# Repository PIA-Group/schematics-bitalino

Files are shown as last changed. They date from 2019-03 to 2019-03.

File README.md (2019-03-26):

# BITalino Schematics

PCB schematics and physical drawings for the original BITalino (https://www.bitalino.com) biomedical development toolkit, which includes Molex Sherlock connectors footprint and pin
breakout. Source files (.brd & .sch) can be opened with AutoDesk's EAGLE PCB design software: https://www.autodesk.com/products/eagle/overview

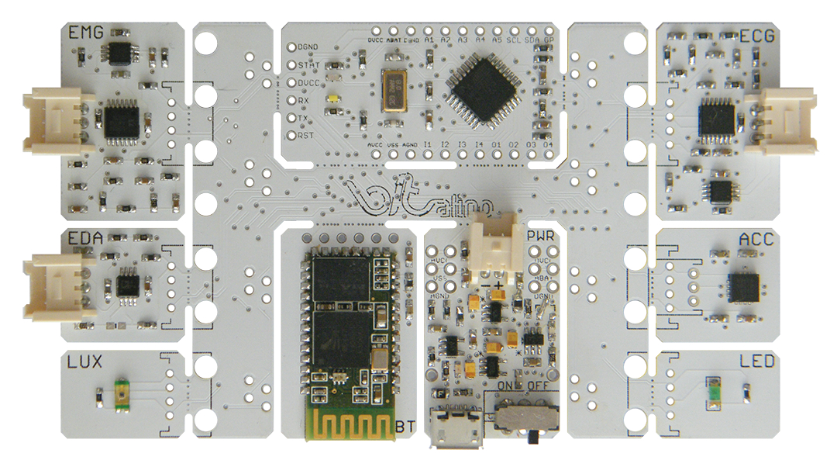
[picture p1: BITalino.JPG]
BITalino All-in-One Board


## Publications

Diana Baptista, Hugo Plácido da Silva and Ana Fred. [Experimental Characterization and Analysis of the BITalino Platforms Against a Reference Device](https://ieeexplore.ieee.org/abstract/document/8037344/). In *Proc. of the IEEE Engineering in Medicine and Biology Society Annual Int’l Conf. (EMBC)*, pp. 2418-2421, 2017

Hugo Plácido da Silva, Carlos Carreiras, André Lourenço, Ana Fred, Rui César das Neves and Rui Ferreira. [Off-the-person electrocardiography: performance assessment and clinical correlation](https://link.springer.com/article/10.1007%2Fs12553-015-0098-y). *Health and Technology*, 4(4), pp. 309-318, Springer, 2015

Hugo Plácido da Silva, Ana Fred and Raúl Martins. [Biosignals for Everyone](https://ieeexplore.ieee.org/xpl/articleDetails.jsp?arnumber=6926682). *IEEE Pervasive Computing*, 13(4):64-71, 2014

Hugo Plácido da Silva, André Lourenço, Ana Fred and Raúl Martins. [BIT: Biosignal Igniter Toolkit](https://sciencedirect.com/science/article/pii/S0169260714000984). *Computer Methods and Programs in Biomedicine*, 115(1):20-32, 2014

Hugo Plácido da Silva, José Guerreiro, André Lourenço, Ana Fred and Raúl Martins. [BITalino: A novel hardware framework for physiological computing](https://www.researchgate.net/publication/260987402_BITalino_A_Novel_Hardware_Framework_for_Physiological_Computing). In *Proc. of the Int’l Conf. on Physiological Computing Systems (PhyCS)*, pp. 246-253, 2014

José Guerreiro, André Lourenço, Hugo Plácido da Silva and Ana Fred. [Performance comparison of low-cost hardware platforms targeting physiological computing applications](https://it.pt/papconf_abs_p.asp?ID_PaperConference=14722&id=4). In *Proc. of the Conf. on Electronics, Telecommunications and Computers (CETC)*, 2013

José Guerreiro, Raúl Martins, Hugo Plácido da Silva, André Lourenço and Ana Fred. [BITalino: A multimodal platform for physiological computing](https://www.researchgate.net/publication/259177489_BITalino_A_Multimodal_Platform_for_Physiological_Computing). In *Proc. of the Int’l Conf. on Informatics in Control, Automation and Robotics (ICINCO)*, pp. 500-506, 2013

Priscila Alves, Hugo Plácido da Silva, André Lourenço and Ana Fred. [BITalino: A biosignal acquisition system based on the Arduino](https://lx.it.pt/~afred/papers/BITalino.pdf). In *Proc. of the Int'l Conf. on Biomedical Electronics and Devices (BIODEVICES)*, pp. 261-264, 2013

## License

See LICENSE for more details.

## Disclaimer

This work is distributed in the hope it will be useful and provided
to you "as is", but WITHOUT ANY WARRANTY, without even the implied
warranty of MERCHANTABILITY or FITNESS FOR A PARTICULAR PURPOSE. This
work is NOT intended for medical diagnosis. We expressly disclaim any
liability whatsoever for any direct, indirect, consequential, incidental
or special damages, including, without limitation, lost revenues, lost
profits, losses resulting from business interruption or loss of data,
regardless of the form of action or legal theory under which the
liability may be asserted, even if advised of the possibility of such
damages.

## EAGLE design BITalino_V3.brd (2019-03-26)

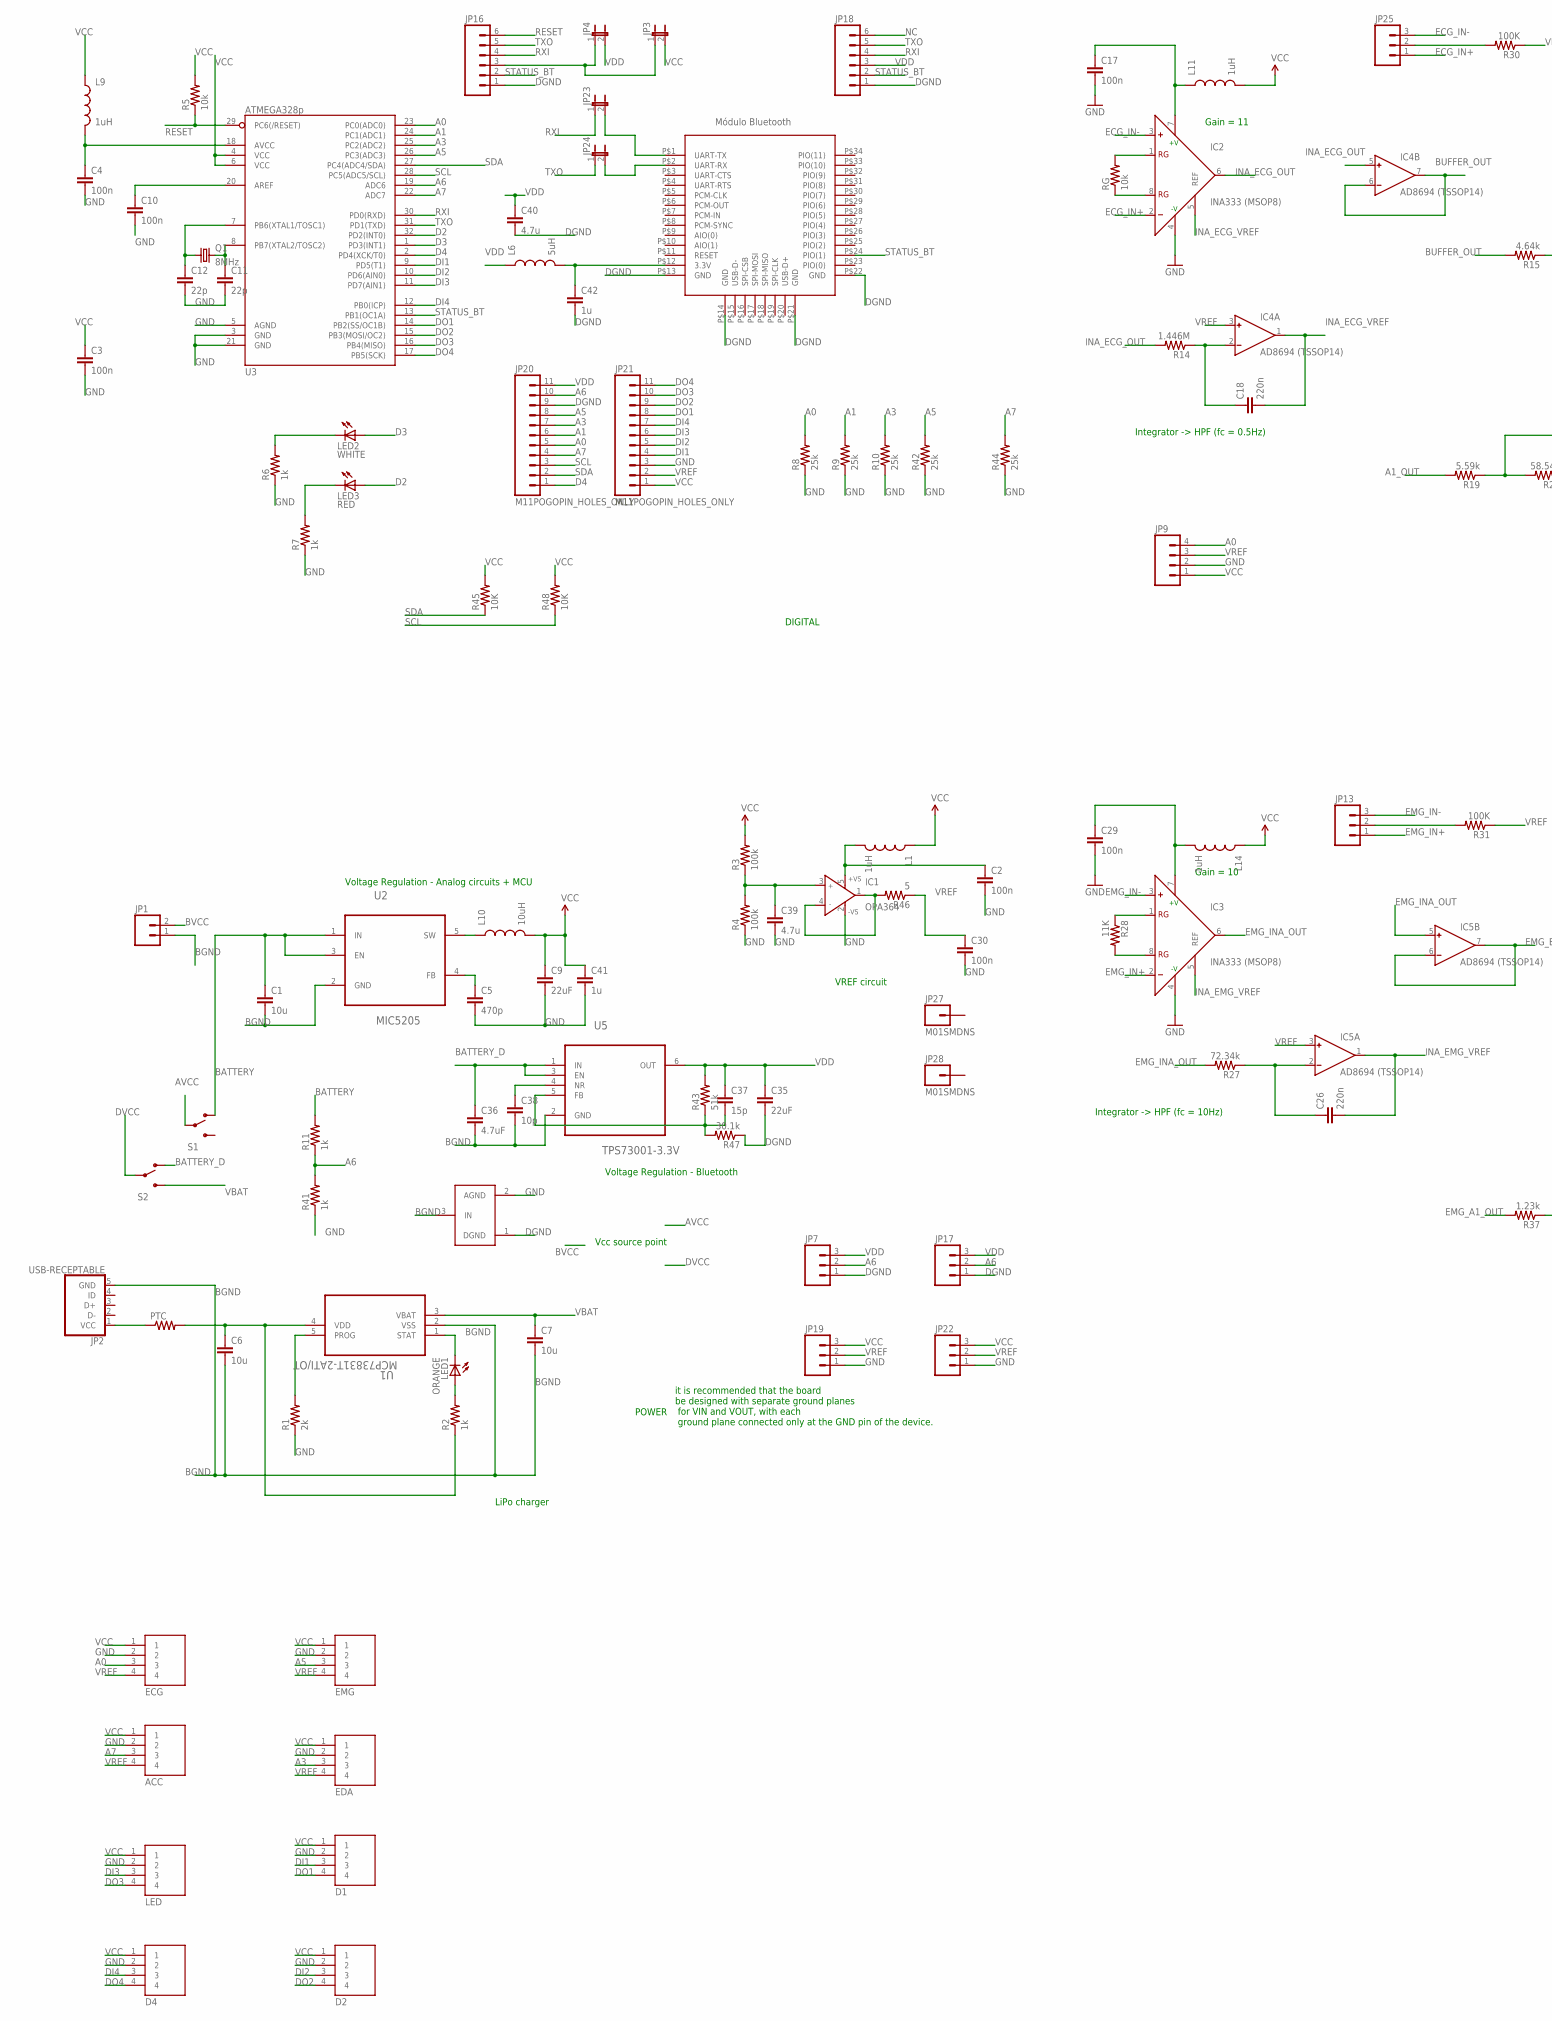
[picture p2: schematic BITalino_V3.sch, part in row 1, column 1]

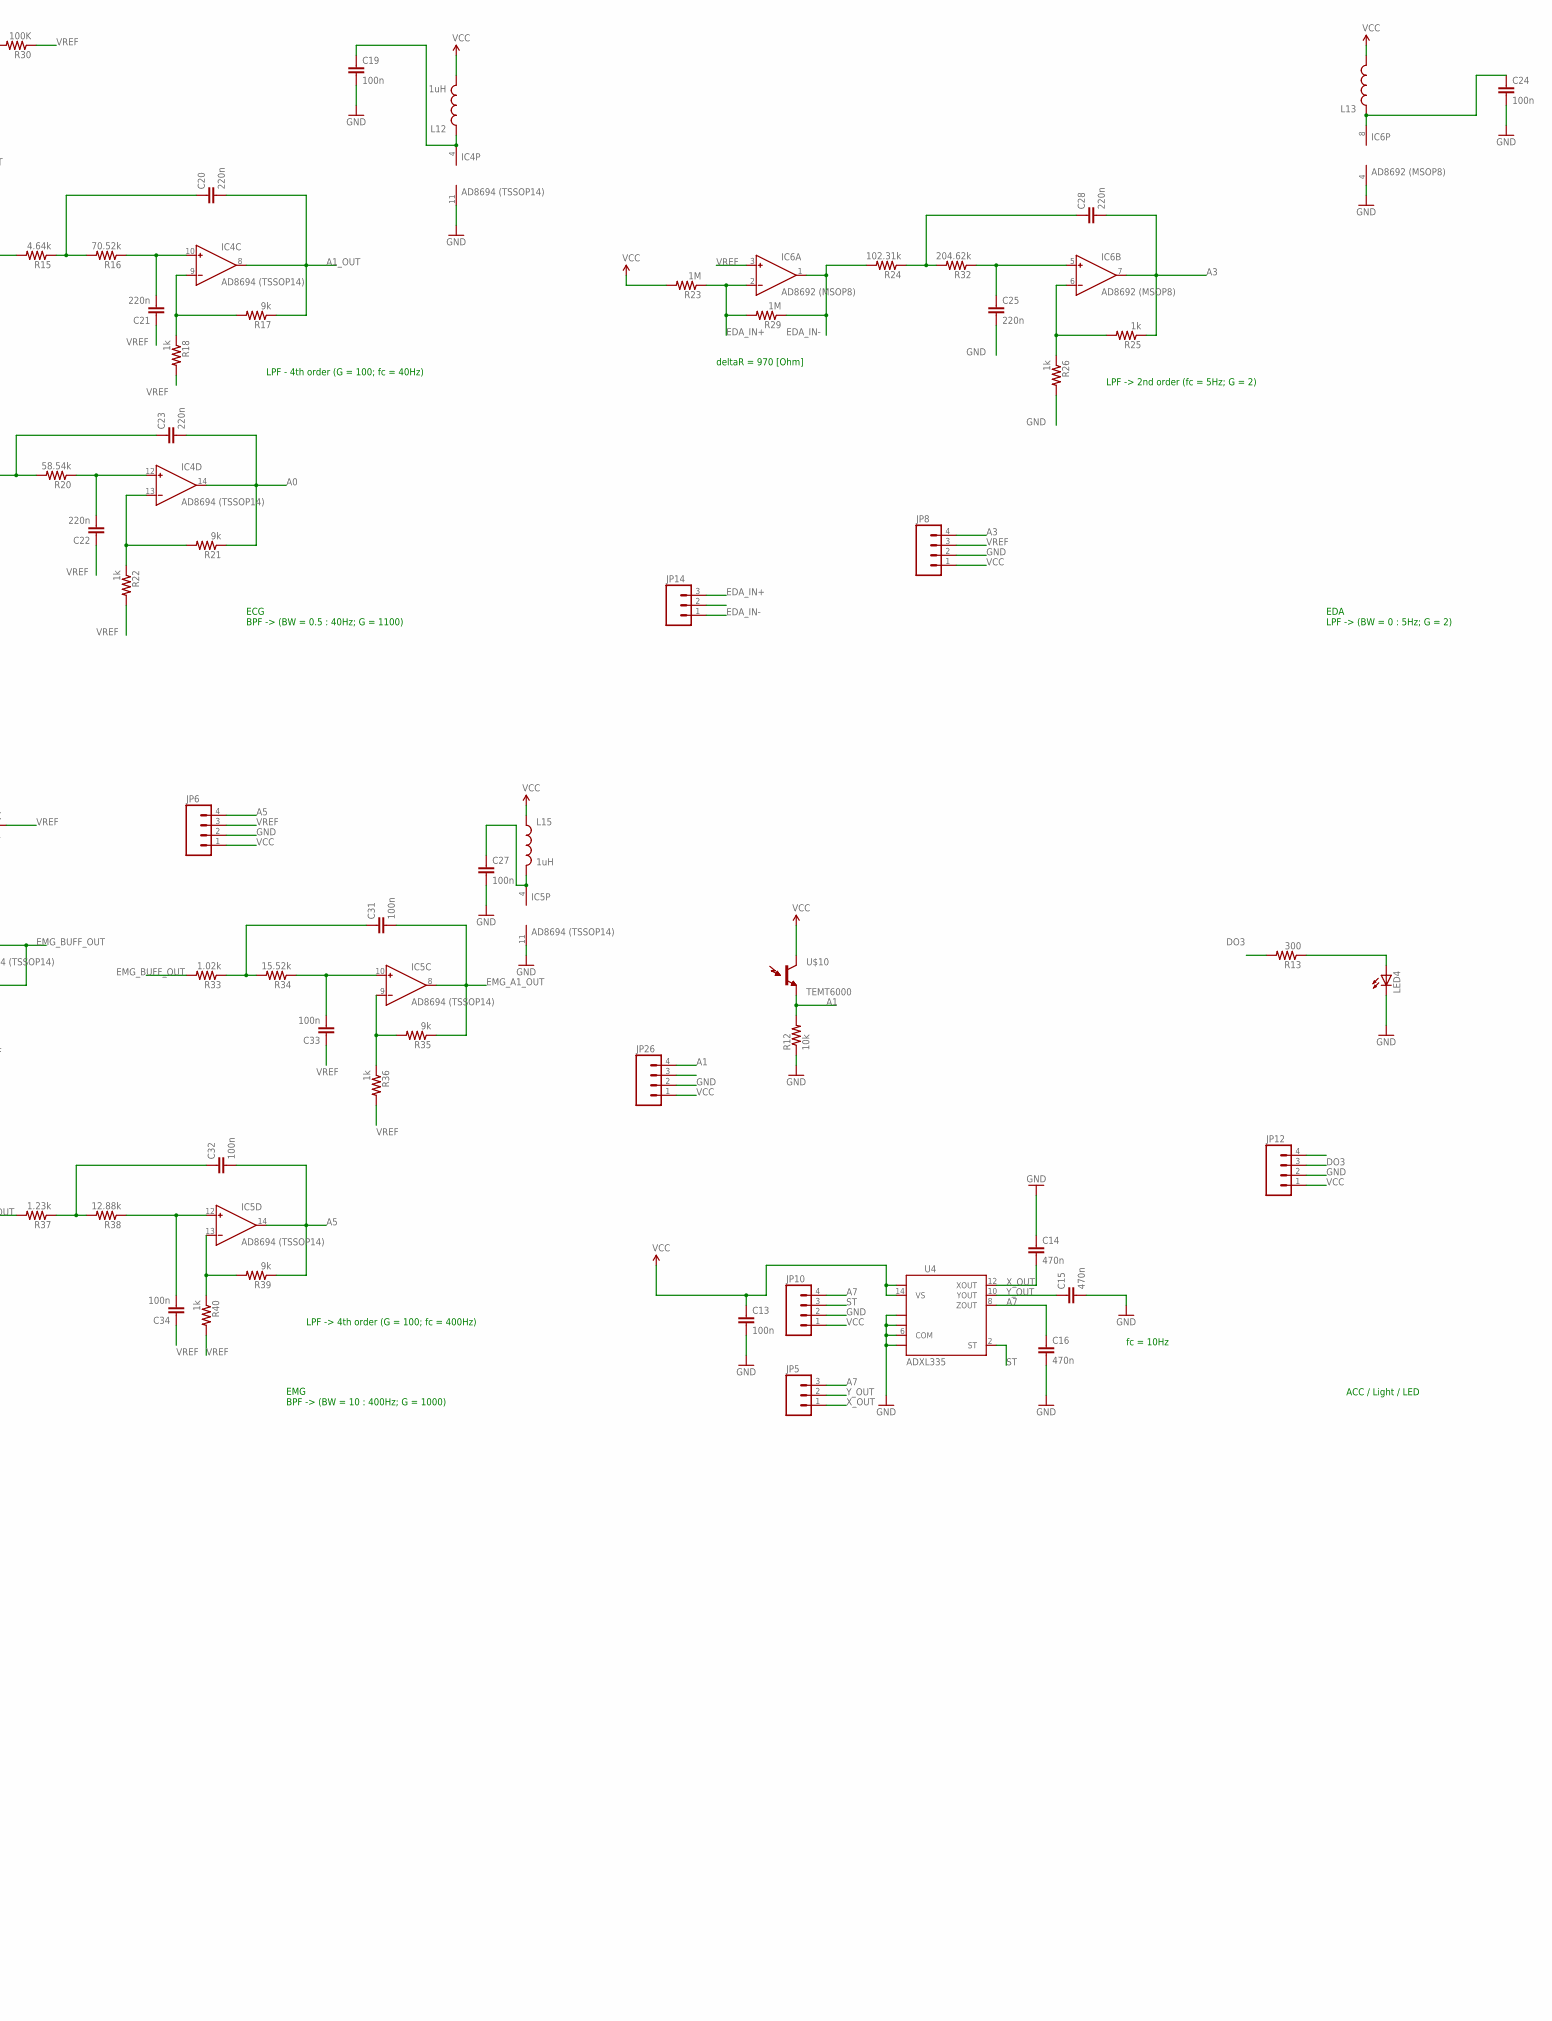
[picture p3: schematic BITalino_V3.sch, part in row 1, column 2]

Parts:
ACC: RJ22; SMD
C1, C6, C7: 10u; 0805
C2, C3, C4, C10, C13, C17, C19, C24, C27, C29, C30, C31, C32, C33, C34: 100n; 0603-CAP
C5: 470p; 0603-CAP
C9, C35: 22uF; 0805
C11, C12: 22p; 0603-CAP
C14, C15, C16: 470n; 0603-CAP
C18, C20, C21, C22, C23, C25, C26, C28: 220n; 0603-CAP
C36: 4.7uF; 0805
C37: 15p; 0603-CAP
C38: 10p; 0603-CAP
C39, C40: 4.7u; 0603-CAP
C41, C42: 1u; 0603-CAP
D1, D2, D4: RJ22; SMD
ECG: RJ22; SMD
EDA: RJ22; SMD
EMG: ECG; SMD
IC1: OPA364; SOT23-5
IC2, IC3: INA333 (MSOP8); MSOP08
IC4, IC5: AD8694 (TSSOP14); TSSOP14
IC6: AD8692 (MSOP8); MSOP08
JP1: M02-JST-2-PTH-NO_SILK; JST-2-PTH-NS
JP2: USB-RECEPTABLE; FCI-10103594-0001LF
JP3, JP4, JP23, JP24: JUMPER-2SMD-NO-NS; SJ_2S-NO-NS
JP5, JP13, JP14, JP25: M03JST-PTH; JST-3-PTH
JP6, JP8, JP9, JP10, JP12, JP26: M04JST-PTH; JST-4-PTH
JP7, JP17, JP19, JP22: M031X03_NO_SILK; 1X03_NO_SILK
JP16, JP18: M06POGOPIN_HOLES_ONLY; 1X06_HOLES_ONLY
JP20, JP21: M11POGOPIN_HOLES_ONLY; 1X11_HOLES_ONLY
JP27, JP28: M01SMDNS; 1X01NS
L1, L9, L11, L12, L14, L15: 1uH; 0603
L6: 5uH; 0805
L10: 10uH; 0805
L13: INDUCTOR0603; 0603
LED: RJ22; SMD
LED1: ORANGE; LED-0603
LED2: WHITE; LED-0603
LED3: RED; LED-0603
LED4: LED1206; LED-1206
PTC: RESISTOR0805-RES; 0805
Q1: 8MHz; CTS406
R1: 2k; 0603-RES
R2, R6, R7, R11, R18, R22, R25, R26, R36, R40, R41: 1k; 0603-RES
R3, R4: 100k; 0603-RES
R5, R12: 10k; 0603-RES
R8, R9, R10, R42, R44: 25k; 0603-RES
R13: 300; 0603-RES
R14: 1.446M; 0603-RES
R15: 4.64k; 0603-RES
R16: 70.52k; 0603-RES
R17, R21, R35, R39: 9k; 0603-RES
R19: 5.59k; 0603-RES
R20: 58.54k; 0603-RES
R23, R29: 1M; 0603-RES
R24: 102.31k; 0603-RES
R27: 72.34k; 0603-RES
R28: 11K; 0603-RES
R30, R31: 100K; 0603-RES
R32: 204.62k; 0603-RES
R33: 1.02k; 0603-RES
R34: 15.52k; 0603-RES
R37: 1.23k; 0603-RES
R38: 12.88k; 0603-RES
R43: 51k; 0603-RES
R45, R48: 10K; 0603-RES
R46: 5; 0603-RES
R47: 30.1k; 0603-RES
RG: 10k; 0603-RES
S1, S2: SWITCH-SPSTPTH; SWITCH-SPDT
U1: MCP73831T-2ATI/OT; SOT95P300X145-5N
U2: MIC5205; SOT95P280X130-5N; MPN ADP2108AUJZ-3.3-R7
U3: ATMEGA328p; TQFP32-08
U4: ADXL335; LFCSP-16
U5: TPS73001-3.3V; SOT95P280X145-6N
U$1: BLUETOOTH
U$2: GND_CONNECT
U$10: TEMT6000; TEMT6000-SEN

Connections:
A0: C23.2, ECG.3, IC4.14 (OUT), JP9.4, JP20.5, R8.2, R21.1, U3.23 (PC0(ADC0))
A1: JP20.6, JP26.4, R9.2, R12.2, U3.24 (PC1(ADC1)), U$10.EMITTER (E1)
A1_OUT: C20.2, IC4.8 (OUT), R17.1, R19.2
A3: C28.2, EDA.3, IC6.7 (OUT), JP8.4, JP20.7, R10.2, R25.1, U3.25 (PC2(ADC2))
A5: C32.2, EMG.3, IC5.14 (OUT), JP6.4, JP20.8, R39.1, R42.2, U3.26 (PC3(ADC3))
A6: JP7.2, JP17.2, JP20.10, R11.1, R41.2, U3.19 (ADC6)
A7: ACC.3, C16.1, JP5.3, JP10.4, JP20.4, R44.2, U3.22 (ADC7), U4.8 (ZOUT)
AVCC: S1.2
BATTERY: C1.1, R11.2, S1.1 (O), U2.1 (IN), U2.3 (EN)
BATTERY_D: C36.1, S2.1 (O), U5.1 (IN), U5.3 (EN)
BGND: C1.2, C6.2, C7.2, C36.2, C38.2, JP1.1, JP2.5 (GND), U1.2 (VSS), U2.2 (GND), U5.2 (GND), U$2.3 (IN)
BUFFER_OUT: IC4.6 (IN-), IC4.7 (OUT), R15.2
BVCC: JP1.2
D2: LED3.A, U3.32 (PD2(INT0))
D3: LED2.A, U3.1 (PD3(INT1))
D4: JP20.1, U3.2 (PD4(XCK/T0))
DGND: C35.2, C40.2, C42.2, JP7.1, JP16.1, JP17.1, JP18.1, JP20.9, R47.1, U$1.P$13 (GND), U$1.P$14 (GND), U$1.P$21 (GND), U$1.P$22 (GND), U$2.1 (DGND)
DI1: D1.3, JP21.4, U3.9 (PD5(T1))
DI2: D2.3, JP21.5, U3.10 (PD6(AIN0))
DI3: JP21.6, LED.3, U3.11 (PD7(AIN1))
DI4: D4.3, JP21.7, U3.12 (PB0(ICP))
DO1: D1.4, JP21.8, U3.14 (PB2(SS/OC1B))
DO2: D2.4, JP21.9, U3.15 (PB3(MOSI/OC2))
DO3: JP12.3, JP21.10, LED.4, R13.2, U3.16 (PB4(MISO))
DO4: D4.4, JP21.11, U3.17 (PB5(SCK))
DVCC: S2.2
ECG_IN+: IC2.2 (-), JP25.1
ECG_IN-: IC2.3 (+), JP25.3
EDA_IN+: IC6.2 (IN-), JP14.3, R23.1, R29.2
EDA_IN-: IC6.1 (OUT), JP14.1, R24.2, R29.1
EMG_A1_OUT: C31.2, IC5.8 (OUT), R35.1, R37.2
EMG_BUFF_OUT: IC5.6 (IN-), IC5.7 (OUT), R33.2
EMG_IN+: IC3.2 (-), JP13.1
EMG_IN-: IC3.3 (+), JP13.3
EMG_INA_OUT: IC3.6 (OUT), IC5.5 (IN+), R27.2
GND: ACC.2, C2.2, C3.2, C4.2, C5.2, C9.2, C10.2, C11.2, C12.2, C13.2, C14.1, C15.2, C16.2, C17.2, C19.2, C24.2, C25.2, C27.2, C29.2, C30.2, C39.2, C41.2, D1.2, D2.2, D4.2, ECG.2, EDA.2, EMG.2, IC1.2 (-VS), IC2.4 (-V), IC3.4 (-V), IC4.11 (V-), IC5.11 (V-), IC6.4 (V-), JP6.2, JP8.2, JP9.2, JP10.2, JP12.2, JP19.1, JP21.3, JP22.1, JP26.2, LED.2, LED4.C, R1.1, R4.1, R6.1, R7.1, R8.1, R9.1, R10.1, R12.1, R26.2, R41.1, R42.1, R44.1, U3.3 (GND), U3.5 (AGND), U3.21 (GND), U4.3 (COM), U4.5 (COM), U4.6 (COM), U4.7 (COM), U$2.2 (AGND)
INA_ECG_OUT: IC2.6 (OUT), IC4.5 (IN+), R14.2
INA_ECG_VREF: C18.2, IC2.5 (REF), IC4.1 (OUT)
INA_EMG_VREF: C26.2, IC3.5 (REF), IC5.1 (OUT)
unnamed: C6.1, PTC.2, R2.1, U1.4 (VDD)
unnamed: R1.2, U1.5 (PROG)
unnamed: LED1.A, R2.2
unnamed: LED1.C, U1.1 (STAT)
unnamed: L10.1, U2.5 (SW)
unnamed: C39.1, IC1.3 (IN+), R3.1, R4.2
unnamed: C38.1, U5.4 (NR)
unnamed: C10.1, U3.20 (AREF)
unnamed: C12.1, Q1.1, U3.7 (PB6(XTAL1/TOSC1))
unnamed: C11.1, Q1.3 (2), U3.8 (PB7(XTAL2/TOSC2))
unnamed: LED2.C, R6.2
unnamed: JP23.2, U$1.P$1 (UART-TX)
unnamed: JP24.2, U$1.P$2 (UART-RX)
unnamed: LED3.C, R7.2
unnamed: C4.1, L9.2, U3.18 (AVCC)
unnamed: C5.1, U2.4 (FB)
unnamed: IC3.1 (RG), R28.1
unnamed: IC3.8 (RG), R28.2
unnamed: JP3.1, JP4.1, JP16.3
unnamed: C29.1, IC3.7 (+V), L14.2
unnamed: C17.1, IC2.7 (+V), L11.1
unnamed: C27.1, IC5.4 (V+), L15.2
unnamed: JP2.1 (VCC), PTC.1
unnamed: LED4.A, R13.1
unnamed: IC2.1 (RG), RG.2
unnamed: IC2.8 (RG), RG.1
unnamed: C18.1, IC4.2 (IN-), R14.1
unnamed: C21.2, IC4.10 (IN+), R16.1
unnamed: C20.1, R15.1, R16.2
unnamed: IC4.9 (IN-), R17.2, R18.1
unnamed: C37.2, R43.1, R47.2, U5.5 (FB)
unnamed: C19.1, IC4.4 (V+), L12.1
unnamed: C28.1, R24.1, R32.2
unnamed: C22.2, IC4.12 (IN+), R20.1
unnamed: C23.1, R19.1, R20.2
unnamed: C25.1, IC6.5 (IN+), R32.1
unnamed: IC4.13 (IN-), R21.2, R22.1
unnamed: IC6.6 (IN-), R25.2, R26.1
unnamed: JP25.2, R30.2
unnamed: C2.1, IC1.5 (+VS), L1.2
unnamed: JP13.2, R31.2
unnamed: C24.1, IC6.8 (V+), L13.1
unnamed: C42.1, L6.2, U$1.P$12 (3.3V)
unnamed: IC1.1 (OUT), IC1.4 (IN-), R46.2
unnamed: C26.1, IC5.2 (IN-), R27.1
unnamed: C33.2, IC5.10 (IN+), R34.1
unnamed: C31.1, R33.1, R34.2
unnamed: IC5.9 (IN-), R35.2, R36.1
unnamed: C34.2, IC5.12 (IN+), R38.1
unnamed: C32.1, R37.1, R38.2
unnamed: IC5.13 (IN-), R39.2, R40.1
NC: JP18.6
RESET: JP16.6, R5.1, U3.29 (PC6(/RESET))
RXI: JP16.4, JP18.4, JP23.1, U3.30 (PD0(RXD))
SCL: JP20.3, R48.1, U3.28 (PC5(ADC5/SCL))
SDA: JP20.2, R45.1, U3.27 (PC4(ADC4/SDA))
ST: JP10.3, U4.2 (ST)
STATUS_BT: JP16.2, JP18.2, U3.13 (PB1(OC1A)), U$1.P$24 (PIO(1))
TXO: JP16.5, JP18.5, JP24.1, U3.31 (PD1(TXD))
VBAT: C7.1, S2.3 (S), U1.3 (VBAT)
VCC: ACC.1, C3.1, C9.1, C13.1, C41.1, D1.1, D2.1, D4.1, ECG.1, EDA.1, EMG.1, JP3.2, JP6.1, JP8.1, JP9.1, JP10.1, JP12.1, JP19.3, JP21.1, JP22.3, JP26.1, L1.1, L9.1, L10.2, L11.2, L12.2, L13.2, L14.1, L15.1, LED.1, R3.2, R5.2, R23.2, R45.2, R48.2, U3.4 (VCC), U3.6 (VCC), U4.14 (VS), U4.15 (VS), U$10.COLLECTOR (C1)
VDD: C35.1, C37.1, C40.1, JP4.2, JP7.3, JP17.3, JP18.3, JP20.11, L6.1, R43.2, U5.6 (OUT)
VREF: ACC.4, C21.1, C22.1, C30.1, C33.1, C34.1, ECG.4, EDA.4, EMG.4, IC4.3 (IN+), IC5.3 (IN+), IC6.3 (IN+), JP6.3, JP8.3, JP9.3, JP19.2, JP21.2, JP22.2, R18.2, R22.2, R30.1, R31.1, R36.2, R40.2, R46.1
X_OUT: C14.2, JP5.1, U4.12 (XOUT)
Y_OUT: C15.1, JP5.2, U4.10 (YOUT)

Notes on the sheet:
DIGITAL
POWER
Gain = 11
LPF - 4th order (G = 100; fc = 40Hz)
Integrator -> HPF (fc = 0.5Hz)
deltaR = 970 [Ohm]
LPF -> 2nd order (fc = 5Hz; G = 2)
Gain = 10
Integrator -> HPF (fc = 10Hz)
LPF -> 4th order (G = 100; fc = 400Hz)
EMG BPF -> (BW = 10 : 400Hz; G = 1000)
ECG BPF -> (BW = 0.5 : 40Hz; G = 1100)
EDA LPF -> (BW = 0 : 5Hz; G = 2)
ACC / Light / LED
LiPo charger
Voltage Regulation - Analog circuits + MCU
VREF circuit
Voltage Regulation - Bluetooth
fc = 10Hz
it is recommended that the board be designed with separate ground planes for VIN and VOUT, with each ground plane connected only at the GND pin of the device.
Vcc source point

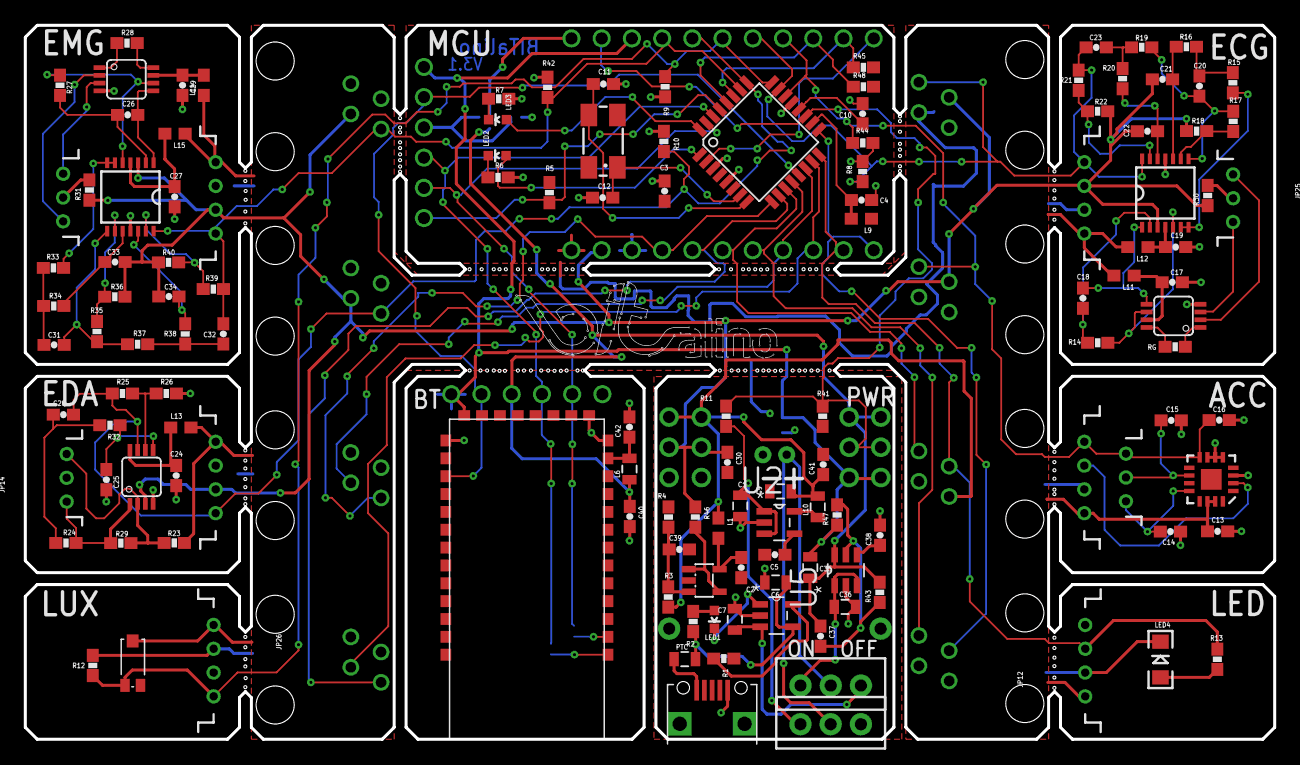
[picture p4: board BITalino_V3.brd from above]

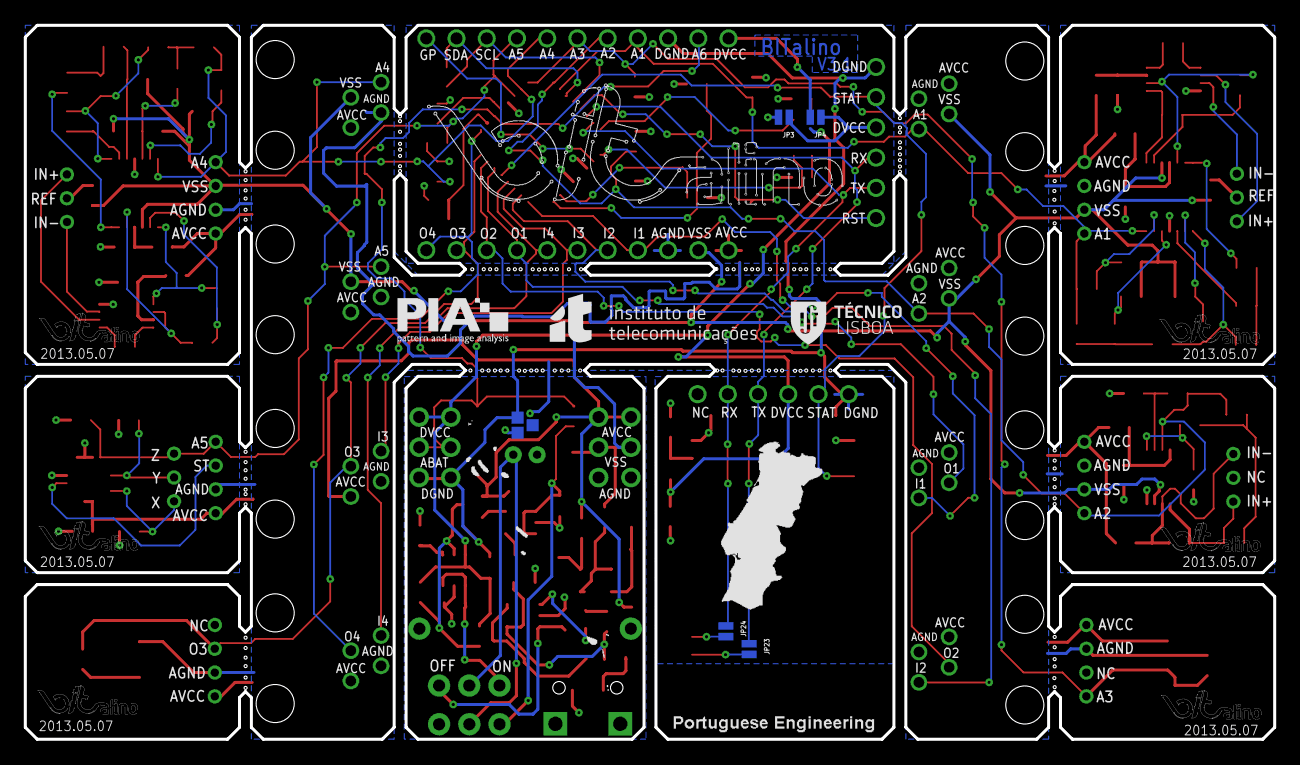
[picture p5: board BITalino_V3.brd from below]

Board: 2 copper layers, 105.0 x 60.0 mm, 167 parts (24 on the bottom side), 100 nets.

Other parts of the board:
U$4: BITALINO_LOGO2
U$5: IT_LOGO
U$6: TECNICO_LOGO
U$7: PIA_LOGO
U$8: BITALINO_LOGO2_SMALL
U$9: PT_IMAGE
U$11, U$12, U$13, U$14, U$15, U$16: BITALINO_LOGO2_SENSORS

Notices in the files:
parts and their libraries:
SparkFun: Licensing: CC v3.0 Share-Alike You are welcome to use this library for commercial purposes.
